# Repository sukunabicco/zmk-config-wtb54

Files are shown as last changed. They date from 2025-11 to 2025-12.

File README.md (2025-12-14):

# WTB54 ダブルトラックボール分割キーボード

   

**54キー分割型・デュアル25mmトラックボール搭載・無線接続対応の自作キーボード**

------

## 📋 目次

- [プロジェクト概要](https://claude.ai/chat/371814f7-e9c6-439c-b8e9-f432d9625389#プロジェクト概要)
- [主な仕様](https://claude.ai/chat/371814f7-e9c6-439c-b8e9-f432d9625389#主な仕様)
- [費用詳細](https://claude.ai/chat/371814f7-e9c6-439c-b8e9-f432d9625389#費用詳細)
- [使用部品リスト](https://claude.ai/chat/371814f7-e9c6-439c-b8e9-f432d9625389#使用部品リスト)
- [必要な工具](https://claude.ai/chat/371814f7-e9c6-439c-b8e9-f432d9625389#必要な工具)
- [組み立て手順](https://claude.ai/chat/371814f7-e9c6-439c-b8e9-f432d9625389#組み立て手順)
- [ファームウェア](https://claude.ai/chat/371814f7-e9c6-439c-b8e9-f432d9625389#ファームウェア)
- [トラブルシューティング](https://claude.ai/chat/371814f7-e9c6-439c-b8e9-f432d9625389#トラブルシューティング)
- [参考資料](https://claude.ai/chat/371814f7-e9c6-439c-b8e9-f432d9625389#参考資料)
- [ライセンス](https://claude.ai/chat/371814f7-e9c6-439c-b8e9-f432d9625389#ライセンス)

------

## 🎯 プロジェクト概要

### コンセプト

WTB54は、**Auto-KDK（Automatic Keyboard Design Kit）** を使用して設計した、デュアルトラックボール搭載の分割型キーボードです。マウスを使わずにすべての操作をキーボード上で完結できる、効率的なワークスタイルを実現します。

### 特徴

- ✅ **54キー分割レイアウト**（左右各27キー）
- ✅ **デュアル25mmトラックボール**（左右に各1個）
- ✅ **無線接続**（Bluetooth対応、nRF52840搭載）
- ✅ **Kailh Choc V2スイッチ対応**（キーピッチ17mm）
- ✅ **ガスケットマウント構造**（打鍵感向上）
- ✅ **カスタマイズ可能なキーマップ**（ZMK Firmware）
- ✅ **バッテリー駆動**（2600mAh Li-Po × 2）

### 設計思想

1. **マウス不要の作業環境** - デュアルトラックボールでカーソル操作とスクロールを同時実現
2. **無線化による省スペース** - ケーブルレスで机上をすっきり
3. **エルゴノミクス** - 分割レイアウトで自然な手の配置
4. **カスタマイズ性** - Auto-KDKによる柔軟な設計変更が可能

------

## 📊 主な仕様

| 項目 | 仕様 |
| --- | --- |
| **レイアウト** | 54キー分割型（左右各27キー） |
| **キーピッチ** | 17mm（Choc V2スイッチ） |
| **トラックボール** | 25mm × 2個（手染め、shakupan製） |
| **センサー** | 14mmマウスセンサーモジュール × 2 |
| **ベアリング** | 2mmセラミックボール × 6個（各3点支持） |
| **スイッチ** | Kailh Mini Linear（Choc V2互換） |
| **キーキャップ** | Junana MX 1U 凹形 × 48個 |
| **コントローラ** | Auto-KDK無線版（nRF52840搭載） × 2 |
| **バッテリー** | 301230 Li-Po 2600mAh × 2 |
| **接続** | Bluetooth 5.0（ZMK Firmware） |
| **ケース** | 3Dプリント（JLC3DP、MJF工法） |
| **マウント** | ガスケットマウント（ポロンシート2mm）  |
| **ファームウェア** | ZMK Firmware |

------

## 💰 費用詳細

### 総費用：¥84,063

内訳を購入先別に記載します。

#### 1. BOOTH（のぎけす屋他）：¥27,470（33%）

| 品名 | 数量 | 単価 | 小計 | 備考 |
| --- | --- | --- | --- | --- |
| Auto-KDK無線版コントローラセット | 2セット | ¥4,625 | ¥9,250  | 専用ボード、コンスルー11ピン×4付属 |
| 自作キーボード設計ガイド電子版 | 2冊 | ¥1,000 | ¥2,000  | Auto-KDK関連ドキュメント |
| 25mmトラックボール（shakupan製） | 2個 | ¥1,385 | ¥2,770  | 手染め、カラー選択可 |
| 14mmマウスセンサーモジュール | 2個 | ¥5,125 | ¥10,250 | PMW3360センサー搭載 |
| Junana MX 1U凹形キーキャップ | 48個 | - | ¥3,200  | ホワイト |

#### 2. Amazon：¥22,444（27%）

| 品名 | 数量 | 単価 | 小計 | 備考 |
| --- | --- | --- | --- | --- |
| TOYOSO T12 Type-C はんだごて | 1個 | ¥5,747 | ¥5,747 | 温度調整可能（200-450℃） |
| UGREEN USB Type-C PD100W 2mケーブル | 1本 | ¥948 | ¥948 | はんだごて電源用 |
| HOZAN スタンドルーペ LPE021 | 1個 | ¥4,377 | ¥4,377 | 作業補助 |
| UGREEN Nexode 65W充電器 | 1個 | ¥2,980 | ¥2,980 | PD対応 |
| CNGINEER ワイヤーストリッパー | 1個 | ¥1,764 | ¥1,764 | 精密作業用 |
| 白光 FH300-81+599B-01セット | 1セット | ¥1,456 | ¥1,456 | はんだごて台＋真鍮クリーナー |
| 白光 こて先 T12-BC2 | 1個 | ¥1,241 | ¥1,241 | 斜めカット型 |
| uxcell セラミックボール 2mm 10個 | 1袋 | ¥889 | ¥889 | トラックボール支持用 |
| HOZAN ピンセット 120mm 880 | 1本 | ¥780 | ¥780 | 精密作業用 |
| Kailh 半田マット 350×250cm | 1枚 | ¥720 | ¥720 | 作業台保護 |
| HOZAN フラックス H-722-P | 1個 | ¥687 | ¥687 | はんだ付け補助剤 |
| goot はんだ吸取線 CP-30Y | 1個 | ¥485 | ¥485 | 修正用 |
| goot はんだ SD-82 0.8mm | 1個 | ¥355 | ¥355 | 鉛フリーはんだ |

#### 3. JLC3DP/JLCPCB：¥12,252（15%）

| 品名 | 数量 | 単価 | 小計 | 備考 |
| --- | --- | ---- | --- | --- |
| PCB基板（左右2枚） | 1セット | - | ¥3,500 | PCBA（ダイオード実装込み） |
| 3Dプリントケース | 4個 | - | ¥8,752 | トップ×2、ボトム×2（MJF工法） |

#### 4. AliExpress：¥8,958（11%）

| 品名 | 数量  | 単価 | 小計 | 備考 |
| --- | ----- | ---- | --- | --- |
| Kailh Mini Linear スイッチ | 110個 | - | ¥4,950 | 使用54個、予備56個 |
| 301230 2600mAh バッテリー JST PH 2.0mm | 4個 | ¥432 | ¥1,728 | 使用2個、予備2個 |
| Outemu Silent Lemon V3 | 90個  | - | ¥2,280 | 別プロジェクト用（MXスイッチ） |

#### 5. 遊舎工房：¥6,544（8%）

| 品名 | 数量  | 単価 | 小計 | 備考 |
| --- | ----- | ---- | --- | --- |
| Kailh Chocソケット（注文#Y99845） | 120個 | - | ¥2,794 | 使用54個、予備66個 |
| ポロンシート2mm レーザー加工（注文#Y100259） | 1枚 | - | ¥3,750 | 500×300サイズ、ガスケット用 |

#### 6. TALP KEYBOARD：¥4,150（5%）

| 品名 | 数量 | 単価 | 小計 | 備考 |
| --- | ---- | --- | --- | --- |
| Seeed Studio XIAO nRF52840 (XIAO BLE) | 2個  | ¥2,075 | ¥4,150 | 別プロジェクト用 |

#### 7. 千石電商：¥2,260（3%）

| 品名 | 数量 | 単価 | 小計 | 備考 |
| --- | ---- | ---- | --- | --- |
| FFC 0.5mm 6ピン 100mm Aタイプ | 4本  | ¥565 | ¥2,260 | トラックボールセンサー接続用 |

------

### 部品区分

| 区分 | 金額 | 比率 |
| --- | --- | ---- |
| **WTB54使用分**  | ¥76,128 | 91%  |
| **別用途・予備** | ¥7,935  | 9% |

**別用途・予備の内訳：**

- XIAO BLE 2個：¥4,150（別プロジェクト用）
- Outemu Silent Lemon V3：¥2,280（MXキーボード用）
- 予備スイッチ56個：¥1,505

------

## 🛠️ 使用部品リスト

### 基板・ケース

- [ ] PCB基板（左右2枚、PCBA実装済み）
- [ ] 3Dプリントケース（トップ×2、ボトム×2）
- [ ] ガスケットマウント用フォーム（ポロンシート2mm、レーザー加工済み）

### コントローラ・電源

- [ ] Auto-KDK無線版コントローラ × 2
- [ ] コンスルー 11ピン（9ピンに加工） × 4
- [ ] 301230 Li-Poバッテリー 2600mAh × 2
- [ ] USB Type-Cケーブル × 1

### スイッチ・キーキャップ

- [ ] Kailh Mini Linear スイッチ × 54
- [ ] Kailh Chocソケット × 54（基板にPCBA実装済みの場合は不要）
- [ ] Junana MX 1U凹形キーキャップ × 48
- [ ] その他キーキャップ × 6（手持ちまたは追加購入）

### トラックボール

- [ ] 25mmトラックボール × 2
- [ ] 14mmマウスセンサーモジュール × 2
- [ ] セラミックボール 2mm × 6
- [ ] FFCケーブル 0.5mm 6ピン 100mm × 4

### その他

- [ ] 滑り止め（ゴム足など）
- [ ] M2ネジ・ナット（必要に応じて）

------

## 🔧 必要な工具

### はんだ付け関連（Chocソケット未実装の場合）

- [ ] はんだごて（温度調整可能、340-350℃推奨）
- [ ] はんだ（0.8mm、鉛フリー）
- [ ] フラックス
- [ ] はんだ吸取線
- [ ] こて先クリーナー（真鍮ウール）
- [ ] はんだごて台

### 作業補助

- [ ] スタンドルーペ（拡大鏡）
- [ ] ピンセット（精密作業用）
- [ ] ニッパー
- [ ] ペンチ
- [ ] プラスドライバー（精密）
- [ ] マスキングテープ
- [ ] 作業マット（耐熱）

### 測定・確認

- [ ] テスター（導通確認用、推奨）
- [ ] ルーペ

### その他

- [ ] 両面テープ（薄手、ガスケットシート固定用）
- [ ] アルコール（清掃用）
- [ ] クリーニングクロス

------

## 📝 組み立て手順

### 事前準備

#### 1. Auto-KDKでの設計

1. [Auto-KDK](https://auto-kdk.pages.dev/)にアクセス
2. キーボードタイプを選択
   - Keyboard Type: Split（分割型）
   - Controller Type: Wireless（無線）
   - Switch Type: Choc V2（キーピッチ17mm）
3. キー配置を編集（54キー、左右各27キー）
4. トラックボールを配置
5. ケースパラメータを調整
6. ファイル出力（zip）

#### 2. 発注

1. **EasyEDA**でPCB基板データを開く
2. **JLCPCB**でPCBA（ダイオード実装）付きで発注
3. **JLC3DP**で3Dプリントケースを発注
4. **遊舎工房**でガスケット用フォームをレーザー加工依頼
5. その他部品をBOOTH、Amazon、AliExpress等で購入

#### 3. 部品到着確認

すべての部品が揃ってから組み立て開始（約2-3週間）

------

### Phase 1: Chocソケット実装（PCBA済みの場合はスキップ）

**所要時間：1.5-2時間**
 **温度設定：340-350℃**

#### 準備

1. YouTube動画で予習
   - [torabo-tsuki組み立て動画](https://youtu.be/21c7hYJnPYo)
   - Chocソケットのはんだ付け部分を重点的に視聴
2. はんだごてを340℃に予熱
3. 作業スペースを整理
   - 換気扇またはサーキュレーター起動
   - 十分な照明確保
   - 工具を手の届く位置に配置

#### 実装作業

1. PCB基板を裏返す（ソケット実装面を上に）
2. ルーペでソケット取り付け位置を確認
3. **片足予備はんだ法**で実装
   - ソケットの片方パッドに予備はんだを盛る
   - ソケットを配置
   - 予備はんだをこて先で溶かしながらソケットを押さえる
   - 固定されたらもう片方をはんだ付け
4. **5個ずつブロック作業**で進める
   - 1ブロック完了ごとに目視確認
   - 4-5ブロック（20-25個）ごとにこて先クリーニング
5. 左手側27個 → 休憩10分 → 右手側27個
6. 全54箇所の最終確認
   - はんだブリッジなし
   - ソケット浮きなし
   - スイッチ仮挿入テスト

**はんだ付けのコツ：**

- こて先を当てる時間：2-3秒以内
- はんだの形状：富士山型を目指す
- パッドとソケットのピンを同時加熱

------

### Phase 2: コントローラ実装

**所要時間：2-3時間**
 **温度設定：340℃**

#### Step 1: コンスルーの加工

1. 付属の11ピンコンスルーを9ピンに加工（4個すべて）
2. 不要なピン2本をペンチで引き抜く
3. 樹脂の突起をニッパーでカット

#### Step 2: コントローラボードの準備

1. Auto-KDK無線版コントローラのレールをペンチで折り取る
2. 左右2個とも実施

#### Step 3: PCB基板にコンスルーを差し込む

**⚠️ 重要：はんだ付けは不要（差し込むだけ）**

1. キーピッチ17mm用の穴を確認（2つ内側の穴）
2. コンスルー2本の小窓の向きを揃える
   - 小窓側が上（PCB基板の表側）
3. 穴に差し込む
4. 垂直性を確認
5. **PCB基板側ははんだ付けしない**（Auto-KDK設計では不要）

#### Step 4: コントローラを差し込む

**⚠️ コントローラ側もはんだ付けしない**

1. コントローラの向きを確認
   - USB-Cコネクタが外側（キーボードの端）向き
   - 表面（LED、チップ）が上
2. コンスルーにしっかり押し込む（カチッと音）
3. 水平性を確認
4. 左右両方実施

#### Step 5: 動作確認

1. USB-Cケーブルを接続
2. 電源スイッチをON
3. LEDが点灯するか確認 ✅

------

### Phase 3: バッテリー配線

**所要時間：30分**
 **⚠️ はんだ付け不要（JST PHコネクタで接続）**

#### バッテリー接続

1. バッテリーの極性を3回確認
   - 赤線：プラス（+）
   - 黒線：マイナス（-）
2. コントローラボードのJST PHコネクタに接続
   - カチッと音がするまで差し込む
   - 無理に力を入れない（正しい向きにスムーズに入る）
3. マスキングテープでバッテリーを軽く固定

#### 動作確認

1. 電源スイッチをON
2. USB-Cケーブル**なし**でLEDが点灯するか確認
   - 点灯した：バッテリー駆動成功 ✅
   - 点灯しない：USB接続で充電してから再確認

------

### Phase 4: FFCコネクタ接続

**所要時間：30分**
 **⚠️ はんだ付け不要（コネクタに差し込むだけ）**

#### 基板側FFCコネクタへの接続

1. FFCコネクタのツメ（黒い部分）を開ける
   - 黒い部分の左右端をつまむ
   - 上に持ち上げる（1-2mm）
2. FFCケーブルの向きを確認
   - 銅箔面（金色）をコネクタの接点側に向ける
3. ケーブルをゆっくり挿入
   - 青い補強部がコネクタの外に出る深さ
   - 銅箔部分が完全にコネクタ内に入る
4. ツメを閉じてロック
   - カチッと音がするまで押す
5. 4箇所すべて実施（左右基板各2箇所）

#### センサーモジュール側への接続

1. 14mmマウスセンサーモジュールのFFCコネクタを開ける
2. FFCケーブルの反対側を接続
3. ツメを閉じてロック
4. 2個のセンサーモジュールで実施

------

### Phase 5: トラックボール組み立て

**所要時間：1時間**

#### Step 1: セラミックボールの配置

1. ケースのトラックボール受け部分を確認
   - 3箇所の穴（120度間隔）
2. セラミックボール2mm × 3個を各穴に配置
   - ピンセットでつまんで慎重に
3. 3個のボールが同じ高さか確認
4. 左右両方で実施（合計6個使用）

#### Step 2: センサーモジュールの固定

1. センサーをトラックボール真下に配置
   - トラックボール底面との距離：1-2mm
2. 固定方法を選択
   - **方法A**：M2ネジで固定（推奨）
   - **方法B**：両面テープで固定
   - **方法C**：ホットボンド（周辺のみ）
3. FFCケーブルを整理
   - 折れ曲がらないように
   - 他の部品と干渉しないように

#### Step 3: トラックボールの設置

1. 25mmトラックボールをセラミックボール上にゆっくり乗せる
2. 3点支持で安定しているか確認
3. 指で軽く回してみる
   - スムーズに回転するか
   - 引っかかりがないか
   - 異音がしないか

------

### Phase 6: スイッチ挿入

**所要時間：30分**

1. トップケースを用意
2. ケースとPCB基板を合わせる
3. スイッチ（Kailh Mini Linear）をソケットに挿入
   - トップケースを挟みながら
   - ピンが曲がっていないか確認
   - カチッと音がするまで押し込む
4. 54個すべて挿入
5. 引っ張って抜けないか確認

------

### Phase 7: ガスケットシート貼り付け

**所要時間：15分**

#### ボトムフォーム

1. ボトムケース内面を清掃（アルコールで拭く）
2. ボトムフォームを配置
   - ケースの形状に合わせる
3. 固定方法を選択
   - **推奨**：接着なし（そのまま挟み込む）
   - **オプション**：四隅に両面テープ
4. PCB基板を乗せる

#### ガスケットフォーム

1. トップケース内側にガスケットフォームを配置
2. ケースの縁に沿わせる
3. 固定方法を選択（接着なしでもOK）

------

### Phase 8: ケース組み立て

**所要時間：30分**

1. ボトムケースにボトムフォーム + PCB基板を配置
2. トップケースを被せる
   - スイッチがケースの穴に合うか確認
3. ボトムケースの爪をトップケースに押し込む
   - 手前から順に
   - パチンと音がするまで
4. 全周確認
   - 隙間がないか
   - 爪がすべてロックされているか

**⚠️ 注意：**

- 爪が大きすぎて入らない場合：ヤスリで少し削る
- 爪が短すぎて緩い場合：手前側にマスキングテープを貼る

------

### Phase 9: 仕上げ

**所要時間：15分**

1. キーキャップを取り付け（54個）
   - カチッと音がするまで差し込む
2. 滑り止めをボトムケースに貼り付け
   - 4隅 + 中央など
   - アルコールで清掃してから貼る
3. 完成！🎉

------

### Phase 10: 最終動作確認

**所要時間：30分**

#### 全キー入力テスト

1. PCとBluetooth接続
   - ペアリングモード起動
   - PCで検出・接続
2. テキストエディタで全54キーを押す
   - すべて反応するか
   - チャタリング（誤入力）がないか

#### トラックボール動作確認

1. カーソルが動くか
   - 上下左右にスムーズか
2. トラックボールの回転確認
   - 引っかかりがないか
   - 異音がしないか

#### Bluetooth接続テスト

1. 左右通信確認
   - 右手側のキーが左手側を通じて入力されるか
2. 接続安定性
   - 途切れないか

#### バッテリー駆動確認

1. USBケーブルを外す
2. バッテリー駆動で動作確認
   - キー入力正常
   - トラックボール正常
3. 充電確認
   - USB接続時に充電LEDが点灯するか

------

## 💻 ファームウェア

### ZMK Firmware

WTB54はZMK Firmwareを使用しています。

#### ファームウェアのビルド

1. Auto-KDKが出力したzipファイルを展開
2. 中身をGitHubにプッシュ
   - リポジトリ名：`zmk-config-wtb54`（任意）
3. GitHub Actionsが自動的にビルド開始
4. ビルド完了後、Artifactsからuf2ファイルをダウンロード

#### ファームウェアの書き込み

1. コントローラの電源スイッチをOFF
2. USB-Cケーブルを接続
   - UF2ブートローダが起動
   - マスストレージとして認識
3. ダウンロードしたuf2ファイルをコピー
   - 左手用：`wtb54_left.uf2`
   - 右手用：`wtb54_right.uf2`
4. 自動的に書き込みが完了
5. ドライブがアンマウントされれば成功

#### キーマップの変更

**方法1：ZMK Studio（GUI）**

1. [ZMK Studio](https://zmk.studio/)にアクセス
2. Bluetooth接続
3. GUIでキーマップを編集

**方法2：ソースコード編集**

1. GitHubリポジトリの`config/wtb54.keymap`を編集
2. Commit & Push
3. GitHub Actionsで再ビルド
4. 新しいuf2ファイルを書き込み

#### トラックボール設定

左トラックボールをスクロールに設定する場合：

```conf
# config/wtb54.conf に追加

CONFIG_ZMK_MOUSE=y
CONFIG_ZMK_POINTING_DEVICE=y
```

詳細は[Auto-KDKトラックボールマニュアル](https://github.com/sekigon-gonnoc/auto-kdk/blob/master/manual/TrackBall.md)を参照。

------

## 🔍 トラブルシューティング

### 組み立て時

| 症状 | 原因 | 対処法 |
| --- | --- | --- |
| スイッチが入らない | ソケット位置ズレ | ソケット再実装 |
| ソケットが浮く | はんだ不足 | 再加熱して追加はんだ |
| はんだブリッジ | はんだ多すぎ | 吸取線で除去 |
| コントローラ認識せず | コンスルー接触不良 | コントローラ挿し直し |

### トラックボール

| 症状 | 原因 | 対処法 |
| --- | --- | --- |
| トラックボールが回らない | センサーに当たっている | センサー位置を下げる |
| 回転が重い | セラミックボール汚れ | アルコールで清掃 |
| 引っかかる | セラミックボール高さ不揃い | 配置を調整 |
| センサーが反応しない | FFC接続不良 | ケーブル挿し直し |
| カーソルが飛ぶ | センサー距離が遠い | センサーを近づける |

### 電源・接続

| 症状 | 原因 | 対処法 |
| --- | --- | --- |
| LEDが点灯しない | バッテリー電圧不足 | USB接続で充電 |
| Bluetooth接続できない  | ファームウェア未書き込み | uf2ファイルを書き込み |
| 充電できない | バッテリー極性逆 | 配線確認（即座に外す） |
| 一部のキーが反応しない | はんだ不良 | 該当ソケット確認・再はんだ |

------

## 📚 参考資料

### 公式ドキュメント

- [Auto-KDK公式サイト](https://auto-kdk.pages.dev/)
- [Auto-KDK GitHub](https://github.com/sekigon-gonnoc/auto-kdk)
- [Auto-KDKトラックボールマニュアル](https://github.com/sekigon-gonnoc/auto-kdk/blob/master/manual/TrackBall.md)
- [ZMK Firmware](https://zmk.dev/)

### 組み立て参考動画

- [torabo-tsuki組み立て動画（せきごん公式）](https://youtu.be/21c7hYJnPYo)
- [秋葉ネオ torabo-tsuki組み立て](https://akiba-neo.com/electronic-work/jisaku-keyboard/2754/)

### コミュニティ

- [自作キーボード温泉街 Discord](https://discord.gg/NM7XtDW)
- [Reddit r/MechanicalKeyboards](https://www.reddit.com/r/MechanicalKeyboards/)

------

## 📸 ギャラリー

（組み立て完成後、写真を追加してください）

------

## 🎓 学んだこと・工夫した点

### 設計段階

- Auto-KDKの柔軟性により、トラックボール配置を最適化
- キーピッチ17mmで省スペース化を実現
- ガスケットマウントで打鍵感を向上

### 組み立て段階

- **はんだ付け不要設計**：コンスルーは差し込むだけで接続可能
- **片足予備はんだ法**：Chocソケット実装の効率化
- **3点支持構造**：セラミックボールによる安定したトラックボール回転

### トラブル対応

- センサー距離の最適化（1-2mm）で検出精度向上
- FFCケーブルの配線整理で断線リスク低減

------

## 🔮 今後の改善案

- [ ] 左トラックボールをスクロール専用に設定（ファームウェア）
- [ ] キーマップの最適化（使用頻度に基づく配置）
- [ ] ロータリーエンコーダーの追加検討
- [ ] OLEDディスプレイの追加検討
- [ ] ケース素材の変更（アルミケース等）

------

## 📜 ライセンス

このプロジェクトはAuto-KDKの出力物であり、以下のライセンスに従います。

- **ハードウェア設計**：Auto-KDK（詳細は[Auto-KDK LICENSE](https://github.com/sekigon-gonnoc/auto-kdk/blob/master/LICENSE)を参照）
- **ファームウェア**：ZMK Firmware（MIT License）

------

## 🙏 謝辞

- **せきごん氏**：Auto-KDKの開発
- **ZMKコミュニティ**：優れたファームウェアの提供
- **自作キーボードコミュニティ**：豊富な情報提供

------

## 📞 お問い合わせ

質問や改善提案がある場合は、GitHubのIssuesまでお願いします。

------

**Built with ❤️ and Auto-KDK**

最終更新：2024年12月15日

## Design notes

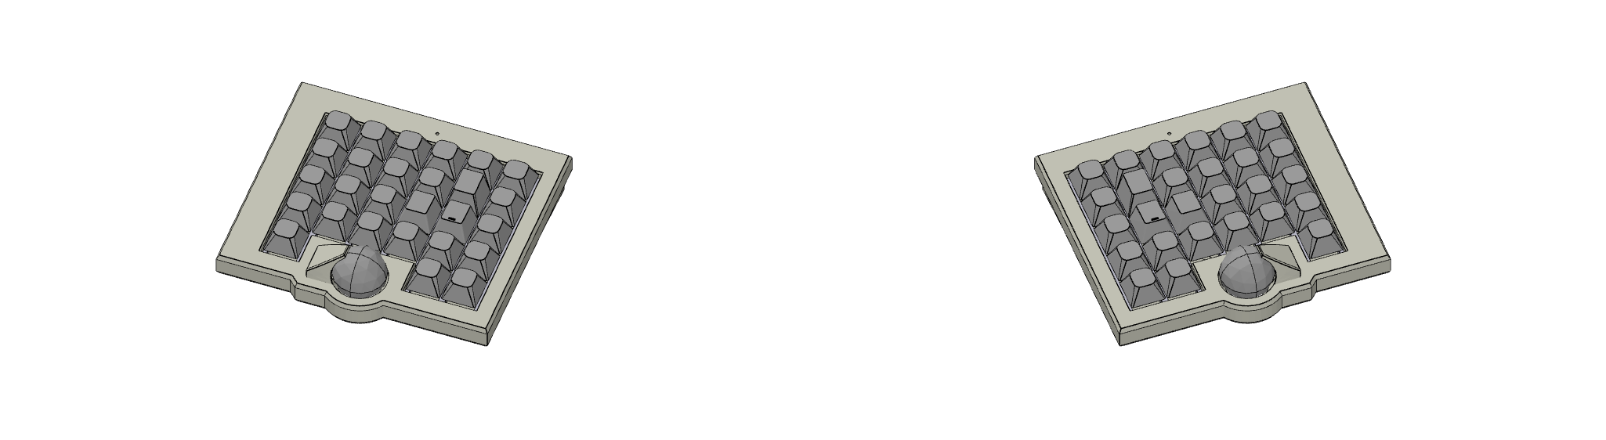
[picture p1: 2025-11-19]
images/WTB54-case-preview.png

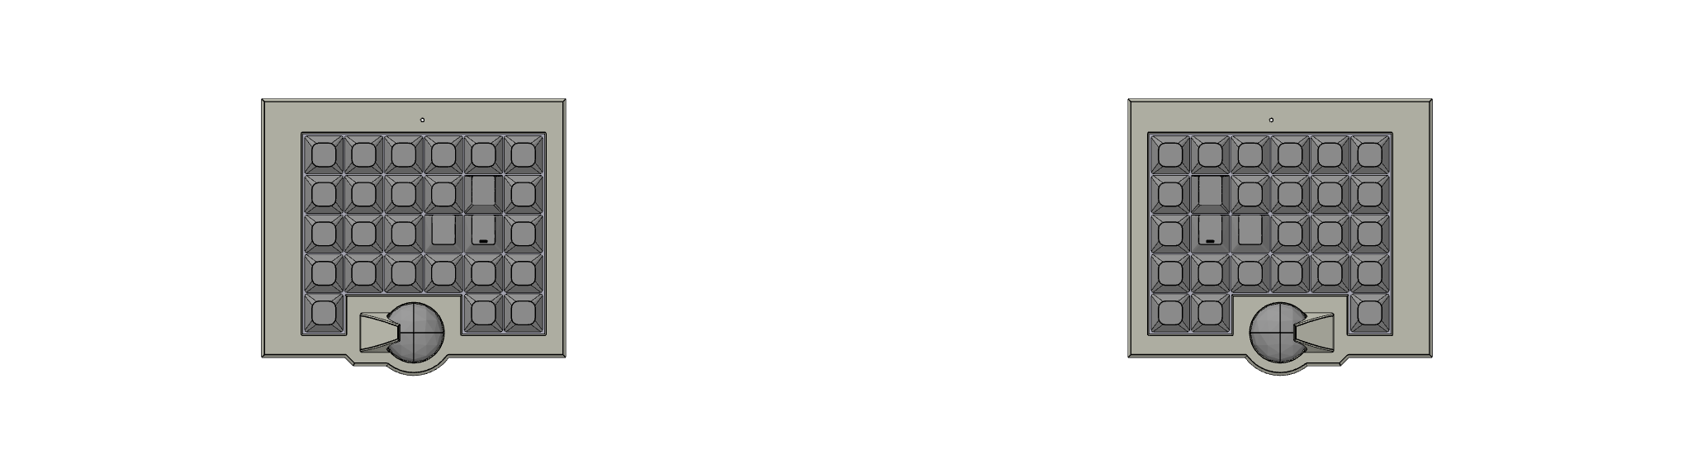
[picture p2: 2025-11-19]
images/WTB54-top-view.png

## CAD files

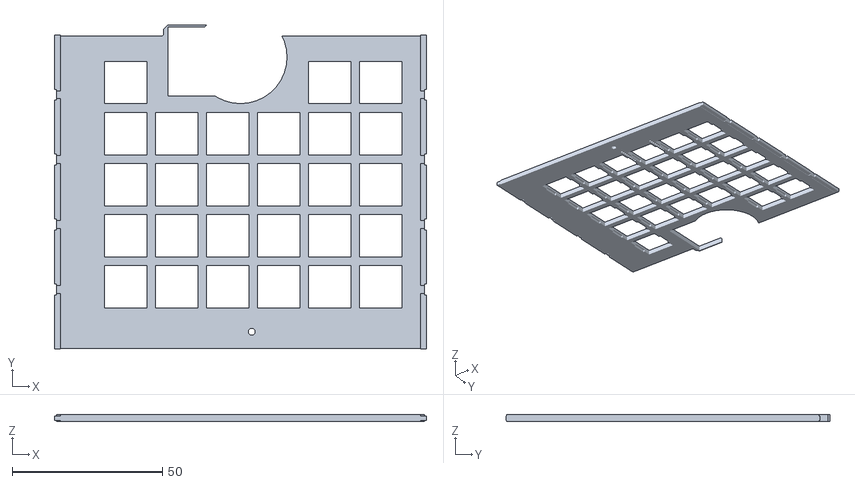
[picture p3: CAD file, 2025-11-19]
case/WTB54-right-plate.stl
123.9 x 108.0 x 2.20

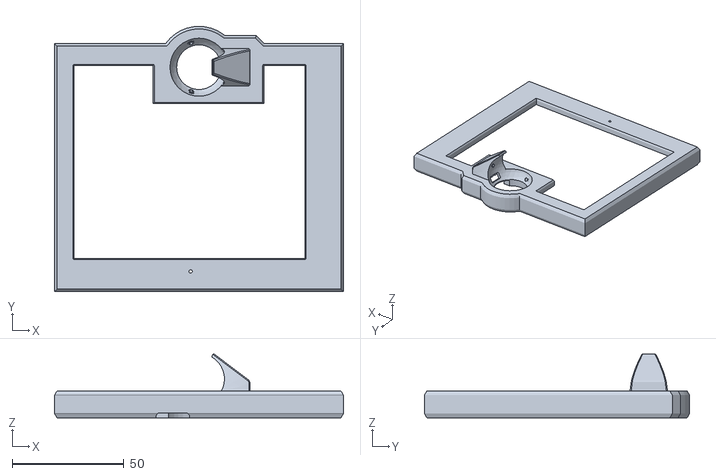
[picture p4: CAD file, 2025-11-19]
case/WTB54-left-top-case.stl
129.5 x 118.9 x 28.7

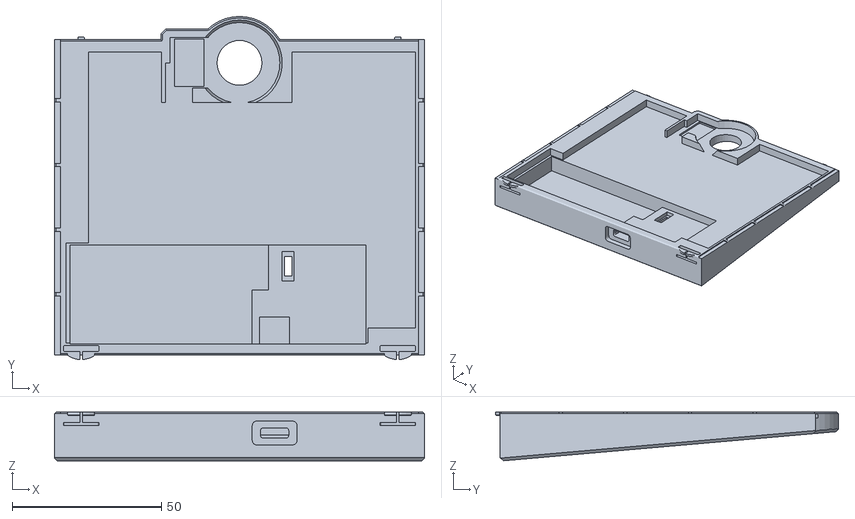
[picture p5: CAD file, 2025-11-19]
case/WTB54-right-bottom-case.stl
123.9 x 114.7 x 16.2

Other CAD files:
case/WTB54-left-plate.stl
case/WTB54-left-bottom-case.stl
case/WTB54-right-top-case.stl

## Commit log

2025-11-19 🎉 Initial commit
    [WTB54-left-bottom-case.stl, WTB54-left-plate.stl, WTB54-left-top-case.stl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]
2025-12-14 fix: Pin ZMK and PAW3222 driver versions to prevent build failures
    - Lock zmk to e34793e (working version from previous successful build)
    - Lock zmk-driver-paw3222 to 9daf613
    - Prevents Kconfig compatibility issues from upstream changes
